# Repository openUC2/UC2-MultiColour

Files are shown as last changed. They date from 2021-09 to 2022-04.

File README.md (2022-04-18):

# openUC2 Multicolour Fluorescence 

Here we present some modules that will help you to first join different laser/light sources using a tunable dichroic mirror and linear dichroic filter switchers. Both modules can direclty snap into the UC2 system.
Curious to see what this looks like? Scroll to the very bottom of the page.

<p align="center">
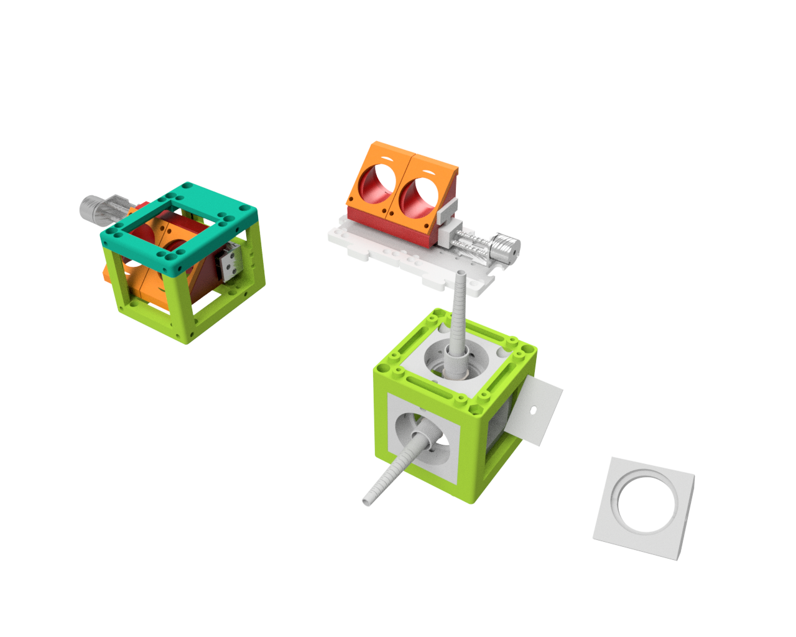
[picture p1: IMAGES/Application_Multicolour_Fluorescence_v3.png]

</p>

**Figure 1:** *(From-left-to-right) Compact linear filter switch that mounts the way that a beam couples from "behind"; same filter switcher, but beam enters from above; Laser beam combiner*

***Features:***
* Switch flourescence filters/dichroics linearly
* Align two beams w.r.t. each other
* Low-cost
* Integrate into the UC2 system

## In-Action

The filter switcher basically works like the one below. This version is deprecated, but the principle remains the same. 

<p align="center">

</p>

# Software

## Firmware 

The laser control and motion of the filter is done by the [UC2-REST](https://github.com/openUC2/UC2-REST) firmware. It is a work-in-progress and we suggest you to reach out to us through an issue when you're keen on using the software

## GUI/Controlsoftware

We forked the beautiful [ImSwitch](https://github.com/kasasxav/ImSwitch/) and adapted many functionalities (e.g. Filter swtichting) into their framework. The [beniroquai fork](https://github.com/beniroquai/ImSwitch/) implements the above mentioned Firmware [UC2-REST](https://github.com/openUC2/UC2-REST). Also here: It is a work-in-progress and we encourage you to reach out to us if you need help. :-)

## Python Code

A ESP32-Python client to control the motors that are connected to e.g. the CNC-Shield v3 can be found here [ESP32Client.py](https://github.com/openUC2/UC2-REST/blob/master/PYTHON/ESP32Client.py).

# Hardware - Beamcombiner

Below we describe how the device can be build and assembled in order to replicate the whole system as shown in the rendering above. One needs additional parts that can be found in the core [openUC2 repository](https://github.com/openUC2/UC2-GIT).

## Bill of material

Below you will find all components necessary to build the beamcombiner

### 3D printing files

All these files in the folder [./STL/Beamcombiner](./STL/Beamcombiner) need to be printed. We used a Prusa i3 MK3 using PLA Prusament (Galaxy Black) at layer height 0.3 mm and infill 30%.

Additionally you need 1x Cube.

<p align="center">
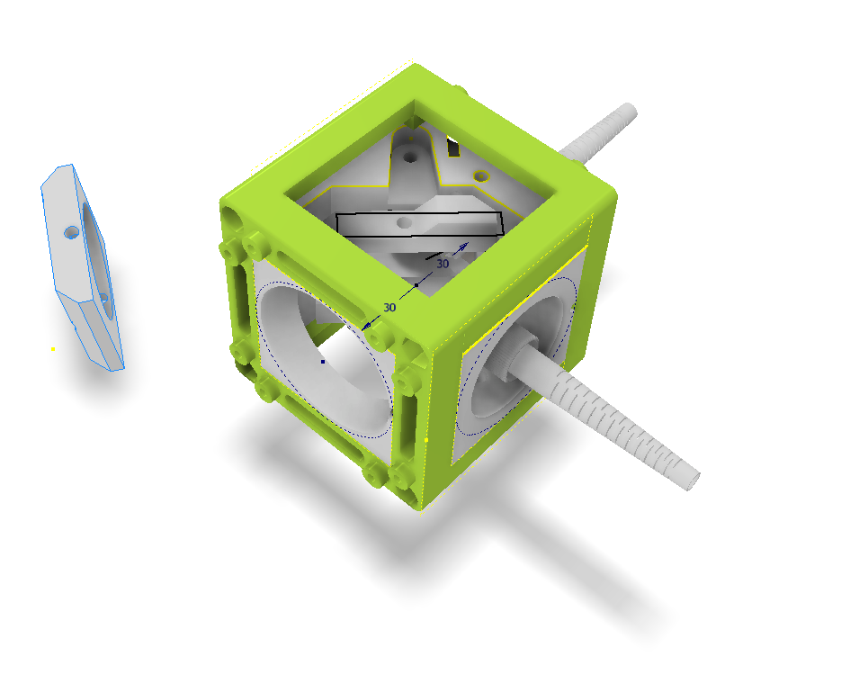
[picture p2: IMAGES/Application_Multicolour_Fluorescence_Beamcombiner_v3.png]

</p>

### Additional parts
This is used in the current version of the setup

|  Type | Details  |  Price | Link  |
|---|---|---|---|
| Dichroic mirror | Depending on your two wavelengths (25mm diameter or 25x16mm, chosoe adapter accordingly) |  10-100 € | [Comar](https://www.comaroptics.com/components/filters/dichroic-filters/long-pass-dichroic-filters)  |
| (optional) Fiber coupled laser | Depending on your system (e.g. MiCost, see SQUID paper) |  10-100 € | [MiCost](micost.com)  |
| (optional) Fiber adapter | 2x Thorlabs SM1FC |  15 € | [Thorlabs](Thorlabs.com)  |
| M3 screws | For kinematic mounting (non magnetic will be ok) |  1 € | [various](amazon.com)  |
| O-ring | 2x to add backtracing force; 10-15mm diameter |  1 € | [various](amazon.com)  |

### Design files
The original design files are in the [INVENTOR](./INVENTOR) folder. 

### Electronics
We develop a dedicated Electronics module called [UC2 Feather](https://github.com/openUC2/UC2_Feather/). Alternatively you can use an ESP32 Wemos d32 in conjuction with an CNC Shield v3.

### Assembly of the DEVICE

***1.*** *These are the parts needed for the DEVICE*

<p align="center">
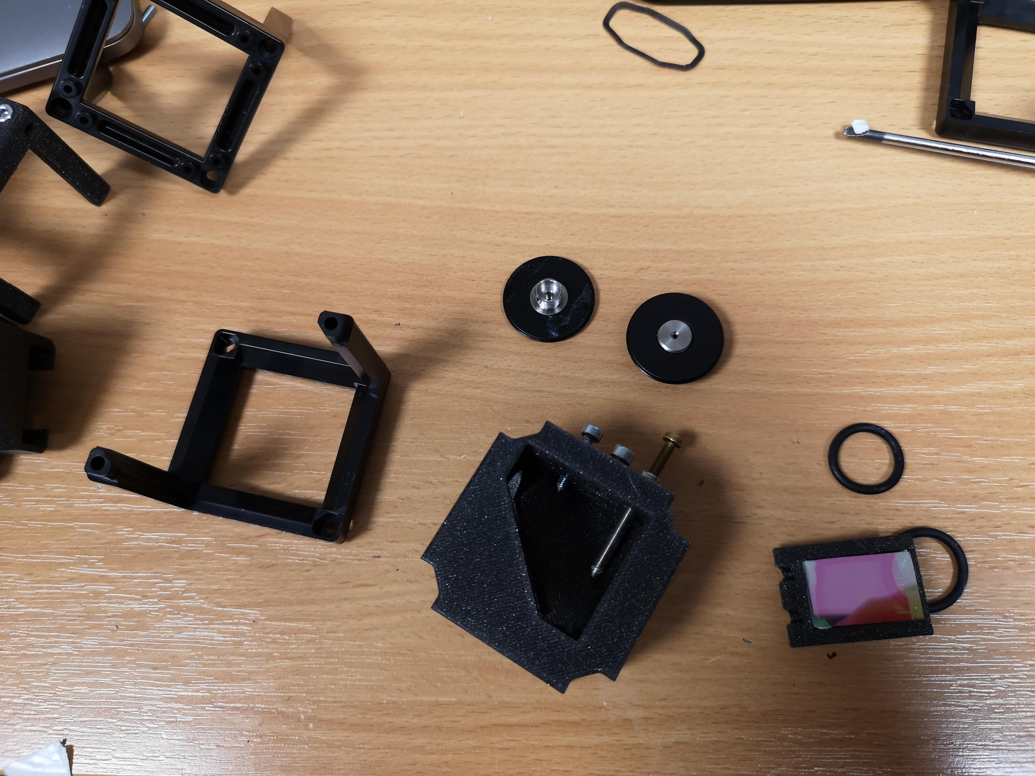
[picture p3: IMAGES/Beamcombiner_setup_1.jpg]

</p>

***2.*** *Start by adding the filter to the holder*

<p align="center">
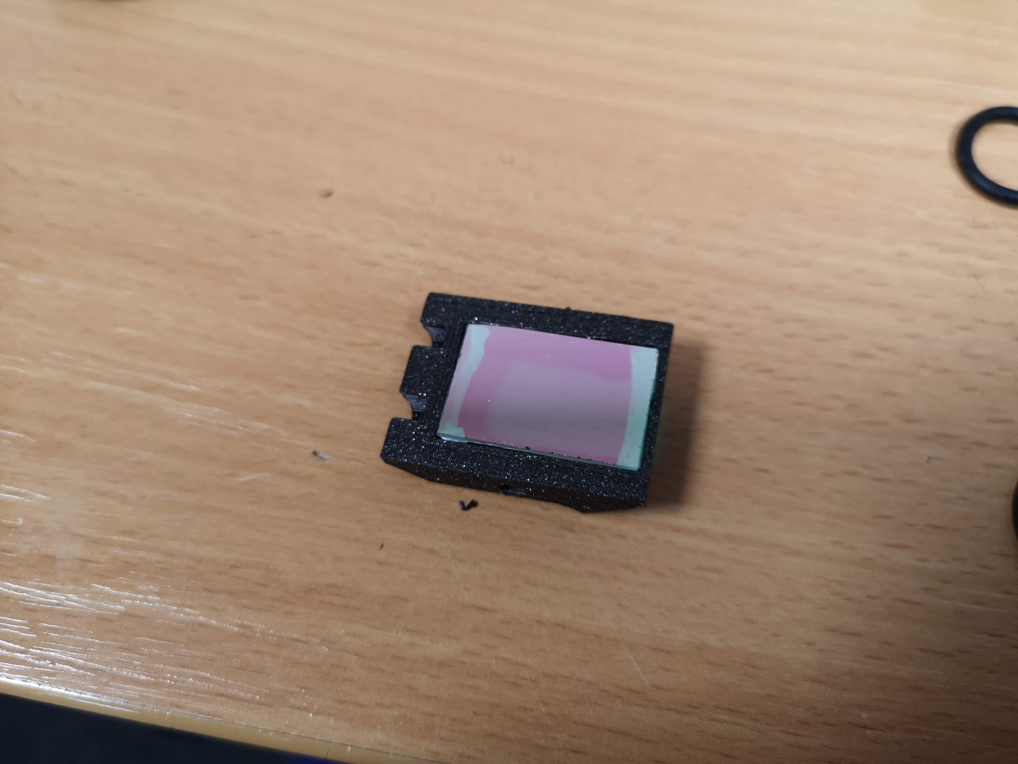
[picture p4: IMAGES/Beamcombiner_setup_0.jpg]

</p>

***3.*** *Add screws everywhere and also add the o-rings* Hint: The screws have been moved to an 45° angle to provide better force ratio (?); If thisneeds more explanation please reach out to us. Hint2: The screws should be pointed so that they fit into the 3D printed grooves from the kinematic mount!

<p align="center">
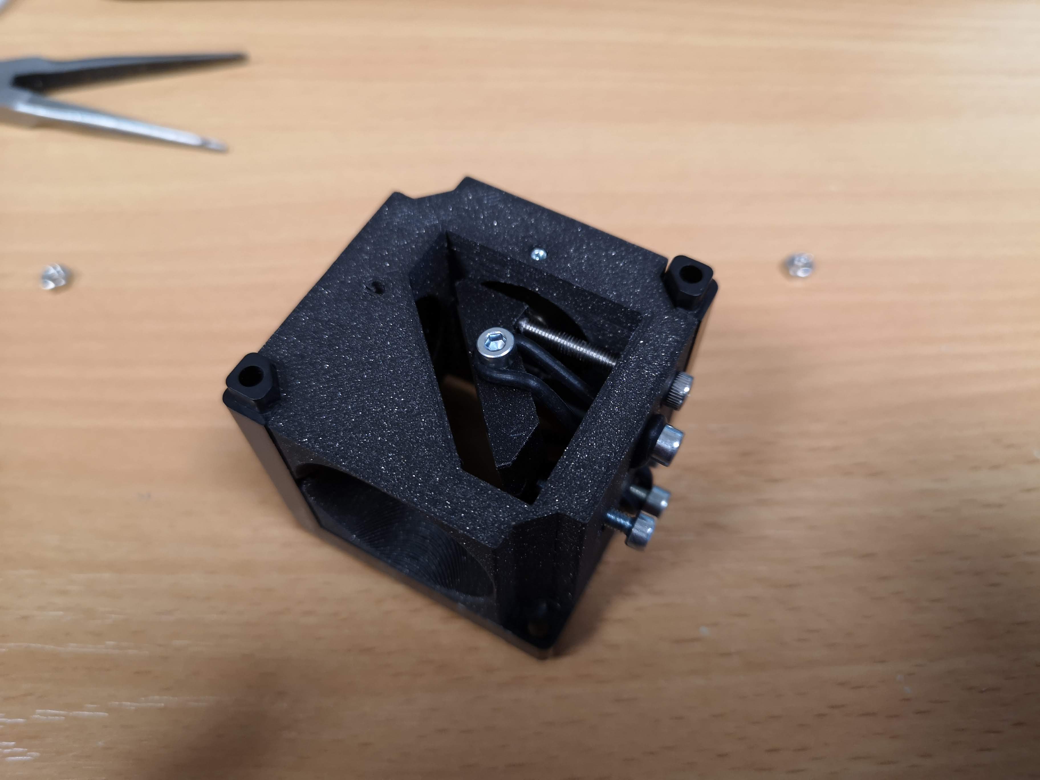
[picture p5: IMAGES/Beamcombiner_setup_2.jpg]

</p>

<p align="center">
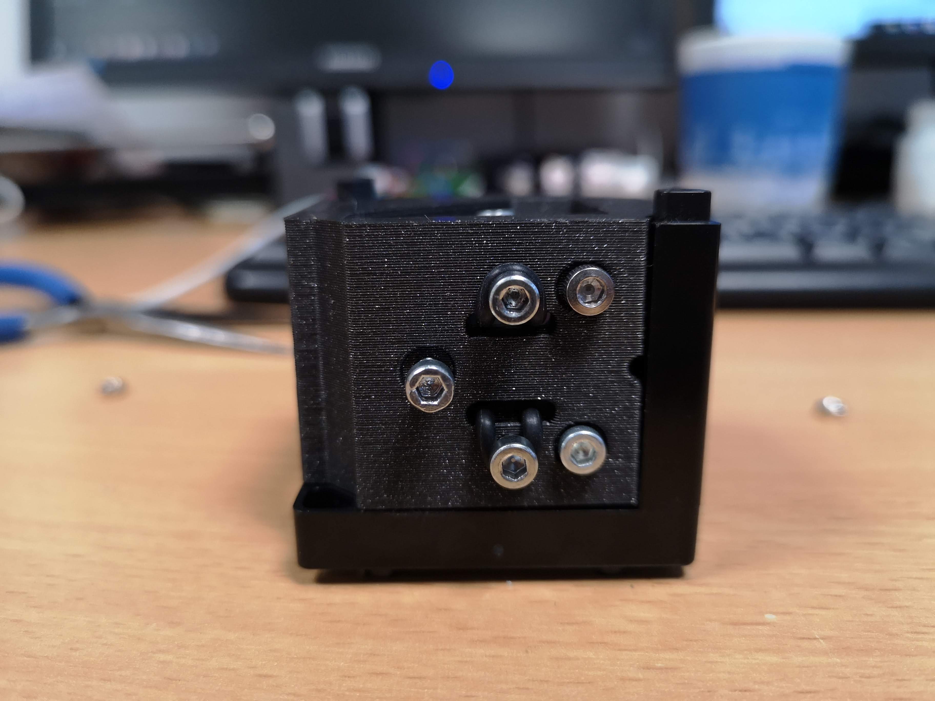
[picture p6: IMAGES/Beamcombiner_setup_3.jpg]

</p>

***4.*** *Add the fiber mounts *

<p align="center">
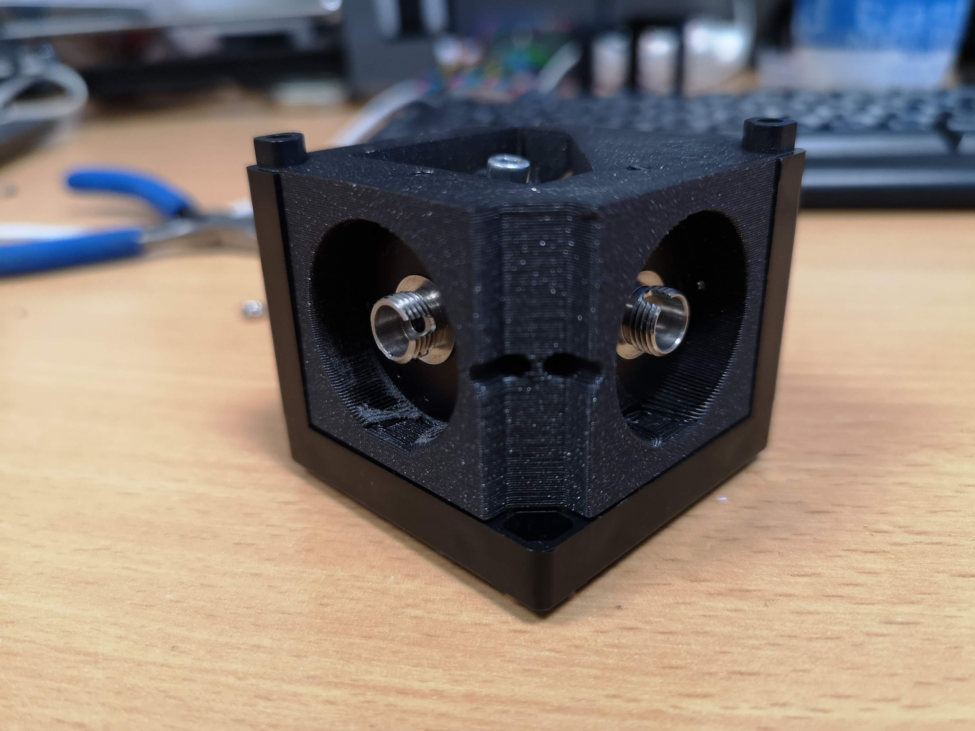
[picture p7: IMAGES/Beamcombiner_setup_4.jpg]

</p>

<p align="center">
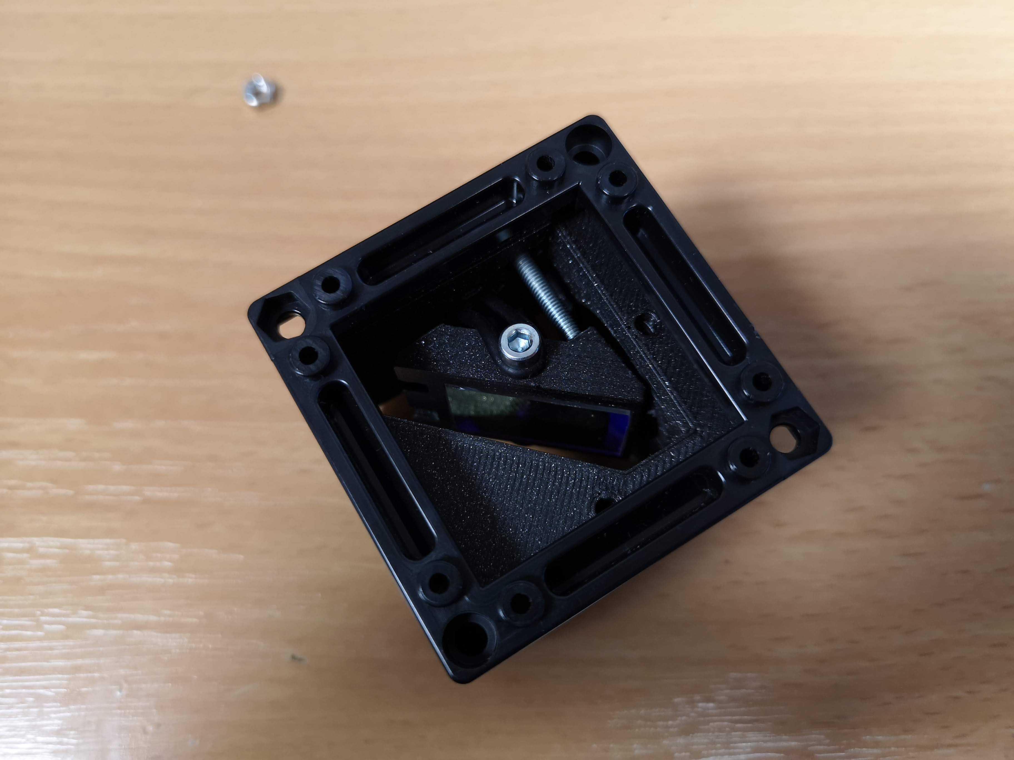
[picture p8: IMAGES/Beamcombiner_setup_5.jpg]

</p>

***5.*** *Add the laser fibers*

<p align="center">
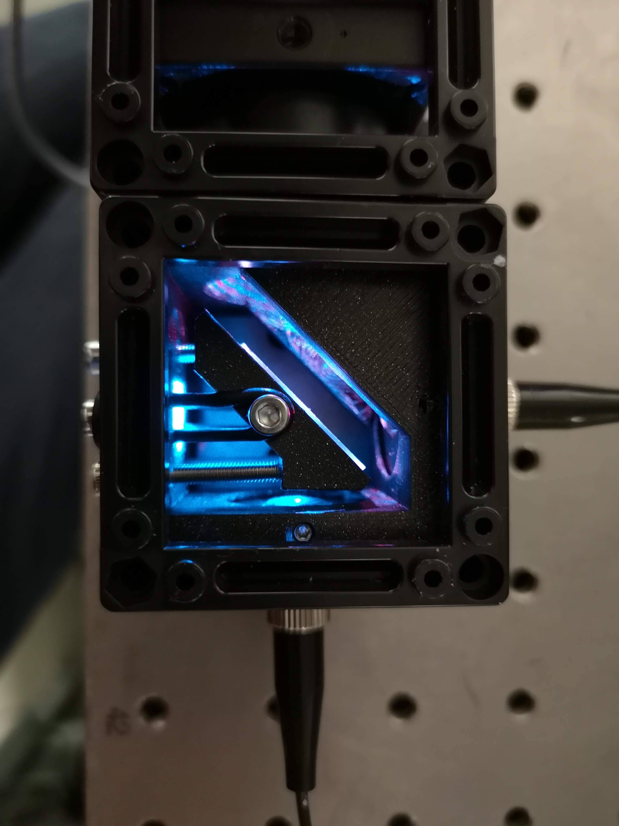
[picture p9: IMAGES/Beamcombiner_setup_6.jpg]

</p>

***6.*** *Align the two beams so that the two circles match perfectly at various places along the optical axis* Hint: Laser safety!

<p align="center">
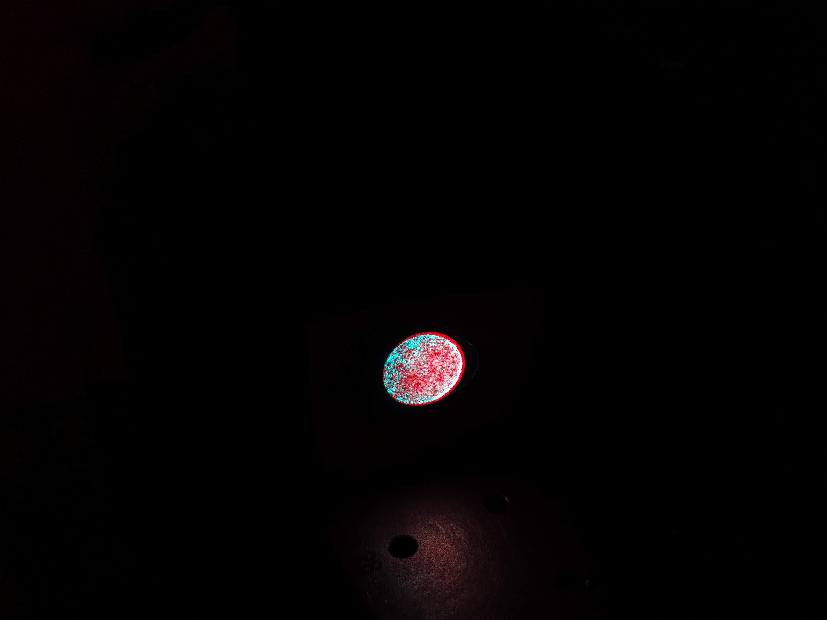
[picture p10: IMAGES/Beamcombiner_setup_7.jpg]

</p>

<p align="center">
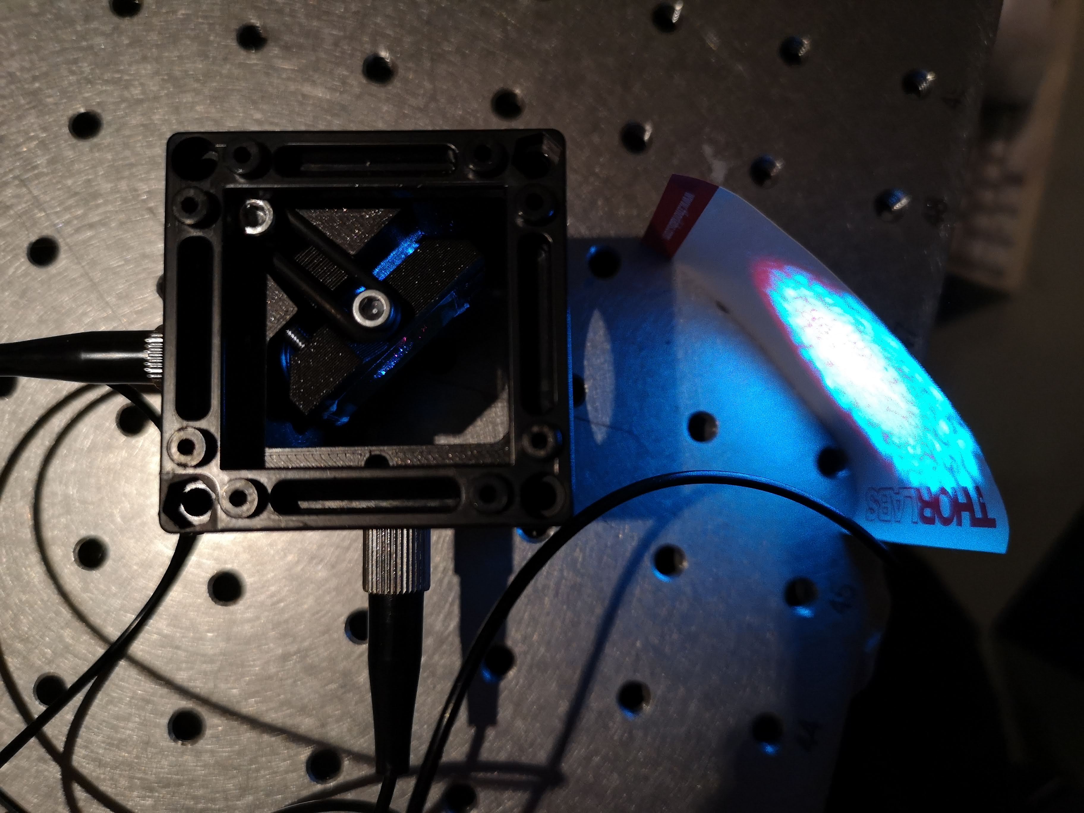
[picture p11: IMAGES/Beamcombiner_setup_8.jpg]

</p>

<p align="center">
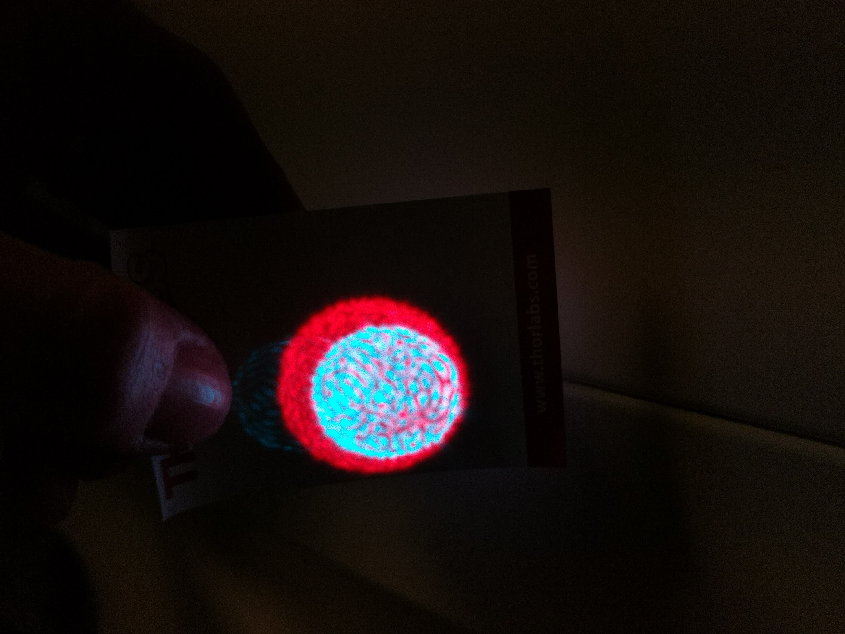
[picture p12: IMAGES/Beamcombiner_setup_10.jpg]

</p>

***7.*** *DONE! LOOK AT THE BEAUTY!*

<p align="center">
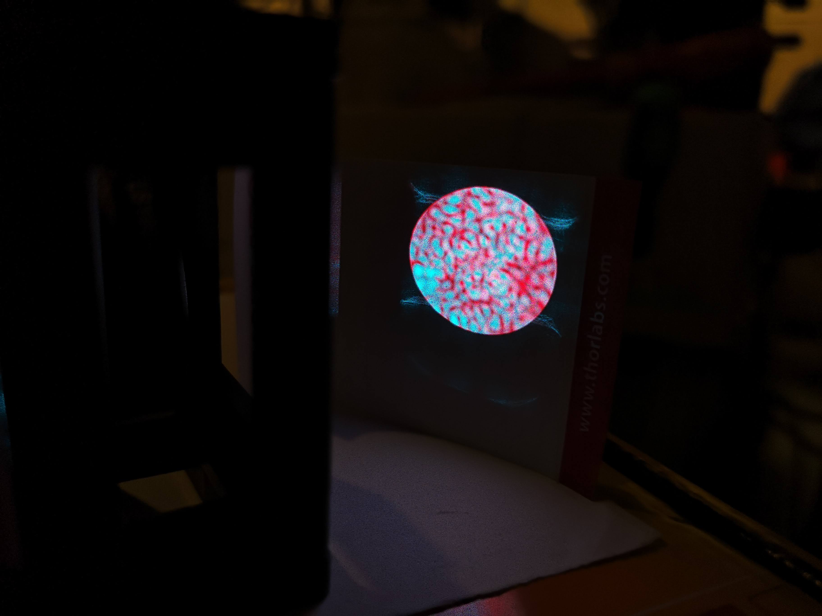
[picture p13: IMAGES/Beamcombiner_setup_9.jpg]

</p>

# Hardware - Beamcombiner

Below we describe how the device can be build and assembled in order to replicate the whole system as shown in the rendering above. One needs additional parts that can be found in the core [openUC2 repository](https://github.com/openUC2/UC2-GIT).

## Bill of material

Below you will find all components necessary to build the beamcombiner

### 3D printing files

All these files in the folder [./STL/Beamcombiner](./STL/Beamcombiner) need to be printed. We used a Prusa i3 MK3 using PLA Prusament (Galaxy Black) at layer height 0.3 mm and infill 30%.

Additionally you need 1x Cube.

<p align="center">

</p>

<p align="center">
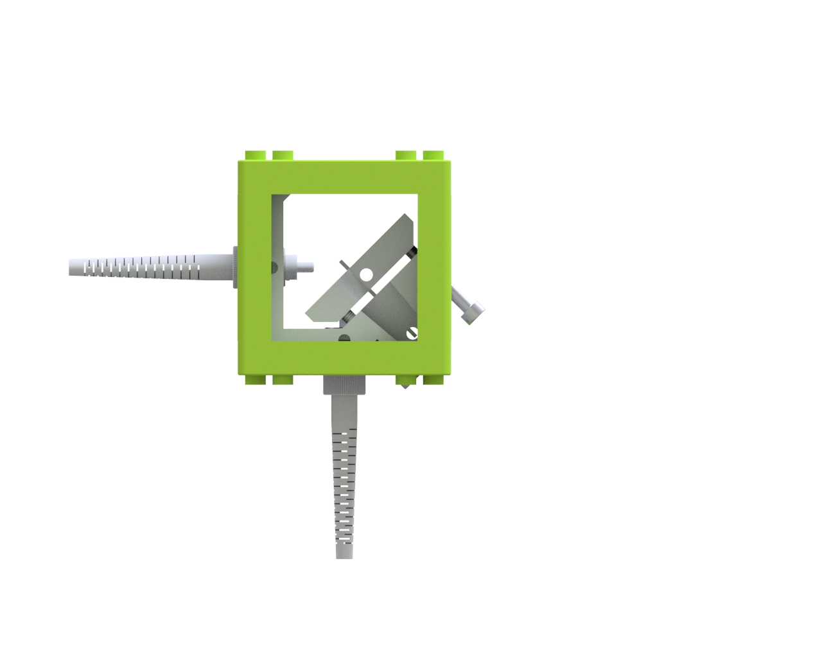
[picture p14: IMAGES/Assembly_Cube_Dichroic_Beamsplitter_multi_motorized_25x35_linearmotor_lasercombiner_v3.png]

</p>

### Additional parts
This is used in the current version of the setup

|  Type | Details  |  Price | Link  |
|---|---|---|---|
| Dichroic mirror | Depending on your two wavelengths (25mm diameter or 25x16mm, chosoe adapter accordingly) |  10-100 € | [Comar](https://www.comaroptics.com/components/filters/dichroic-filters/long-pass-dichroic-filters)  |
| (optional) Fiber coupled laser | Depending on your system (e.g. MiCost, see SQUID paper) |  10-100 € | [MiCost](micost.com)  |
| (optional) Fiber adapter | 2x Thorlabs SM1FC |  15 € | [Thorlabs](Thorlabs.com)  |
| M3 screws | For kinematic mounting (non magnetic will be ok) |  1 € | [various](amazon.com)  |
| O-ring | 2x to add backtracing force; 10-15mm diameter |  1 € | [various](amazon.com)  |

### Design files
The original design files are in the [INVENTOR](./INVENTOR) folder. 

### Electronics
We develop a dedicated Electronics module called [UC2 Feather](https://github.com/openUC2/UC2_Feather/). Alternatively you can use an ESP32 Wemos d32 in conjuction with an CNC Shield v3.

### Assembly of the DEVICE

***1.*** *These are the parts needed for the DEVICE*

<p align="center">

</p>

***2.*** *Start by adding the filter to the holder*

<p align="center">

</p>

***3.*** *Add screws everywhere and also add the o-rings* Hint: The screws have been moved to an 45° angle to provide better force ratio (?); If thisneeds more explanation please reach out to us. Hint2: The screws should be pointed so that they fit into the 3D printed grooves from the kinematic mount!

<p align="center">

</p>

<p align="center">

</p>

***4.*** *Add the fiber mounts *

<p align="center">

</p>

<p align="center">

</p>

***5.*** *Add the laser fibers*

<p align="center">

</p>

***6.*** *Align the two beams so that the two circles match perfectly at various places along the optical axis* Hint: Laser safety!

<p align="center">

</p>

<p align="center">

</p>

<p align="center">

</p>

***7.*** *DONE! LOOK AT THE BEAUTY!*

<p align="center">

</p>

# Hardware - Filterswitcher

Below we describe how the device can be build and assembled in order to replicate the whole system as shown in the rendering above. One needs additional parts that can be found in the core [openUC2 repository](https://github.com/openUC2/UC2-GIT).

## Bill of material

Below you will find all components necessary to build the filterswitcher

### 3D printing files

All these files in the folder [./STL/Beamcombiner](./STL/Beamcombiner) need to be printed. We used a Prusa i3 MK3 using PLA Prusament (Galaxy Black) at layer height 0.1 mm and infill 100%.
For the filter mount it is important to place this surface on the print bed surface so that it is perfectly flat. This way you can make sure that all dichroics are mounted under the same angle. 

Additionally you need several Cubes.

<p align="center">
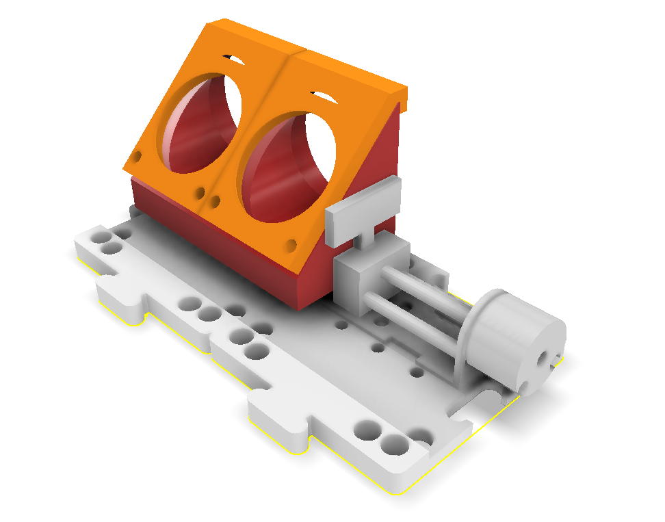
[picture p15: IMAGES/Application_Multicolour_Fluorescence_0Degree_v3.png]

</p>

*Here the beam enters from above (or below, depending on the orientation) and will be reflected horizontally*

<p align="center">
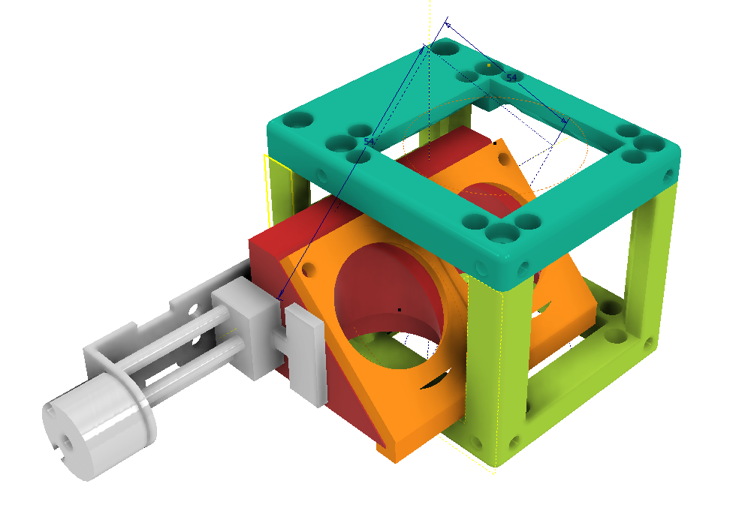
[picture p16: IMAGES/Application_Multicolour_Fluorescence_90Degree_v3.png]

</p>

*Here the beam enters from the side and will be reflected vertically (good for inverted microscopes)*

***HINT***:  you can have 3 filters too

### Additional parts
This is used in the current version of the setup

|  Type | Details  |  Price | Link  |
|---|---|---|---|
| Dichroic mirror | Depending on your two wavelengths (25mm diameter o) |  10-200 € | [Thorlabs](thorlabs.com)  |
| Emission filter | Depending on your two wavelengths (25mm diameter o) |  10-200 € | [Thorlabs](thorlabs.com)  |
| Linear Motor | DC 12V Hub 80mm 
Stepper Screw 2-Phase |  10-100 € | [Amazon](https://www.amazon.de/gp/product/B07X6J8C3T/ref=ox_sc_act_title_1?smid=A119AWRA5YL9T1&psc=1)  |
| M3 screws | For kinematic mounting (non magnetic will be ok) |  1 € | [various](amazon.com)  |
| O-ring | 2x to add backtracing force; 10-15mm diameter |  1 € | [various](amazon.com)  |

### Design files
The original design files are in the [INVENTOR](./INVENTOR) folder. 

### Electronics
We develop a dedicated Electronics module called [UC2 Feather](https://github.com/openUC2/UC2_Feather/). Alternatively you can use an ESP32 Wemos d32 in conjuction with an CNC Shield v3.

### Assembly of the DEVICE

***1.*** *These are the parts needed for the DEVICE*

<p align="center">
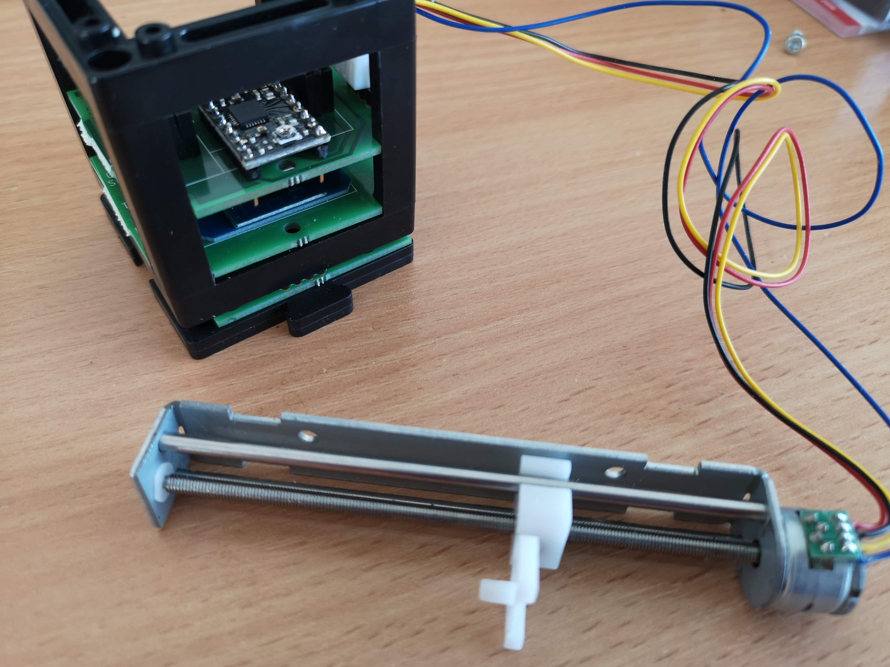
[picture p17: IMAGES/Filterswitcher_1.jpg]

</p>

<p align="center">
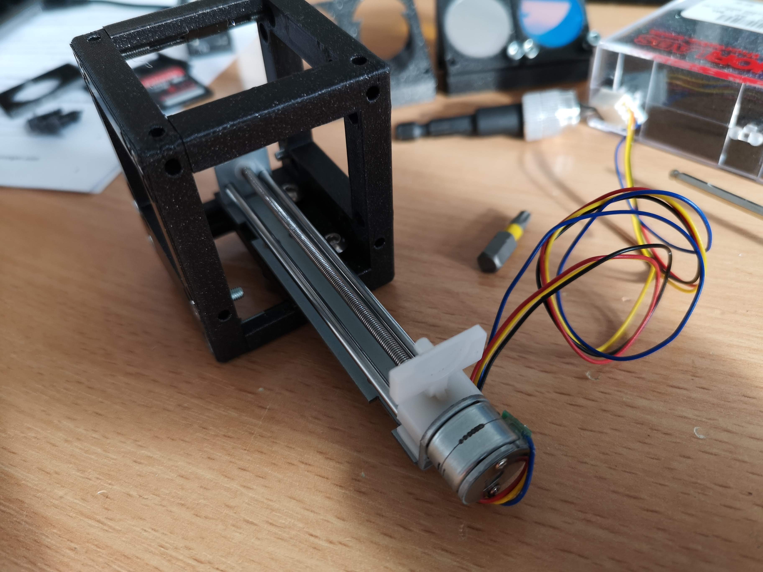
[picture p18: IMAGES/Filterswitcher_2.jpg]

</p>

Here moves the motor, glue the white pin to the filterholder

<p align="center">
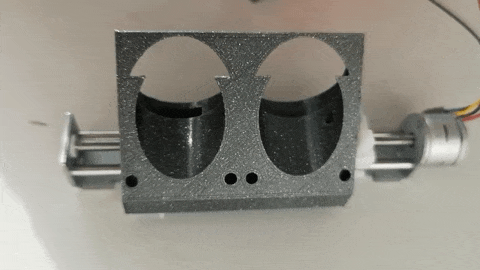
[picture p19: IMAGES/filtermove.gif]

</p>

***2.*** Mount the Slide with M3 screws to the Cube
<p align="center">
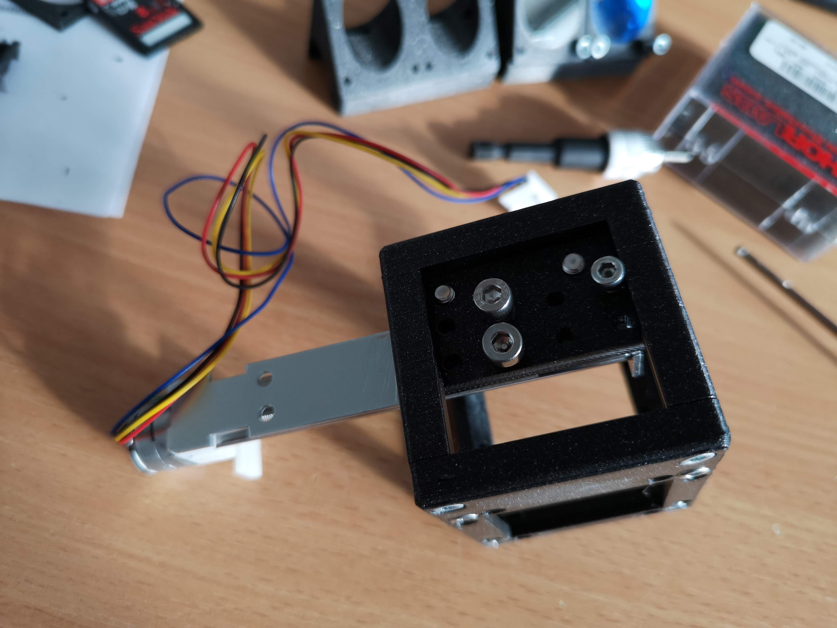
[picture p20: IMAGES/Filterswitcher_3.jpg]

</p>

***3.*** Add the filters with additional M3 screws

<p align="center">
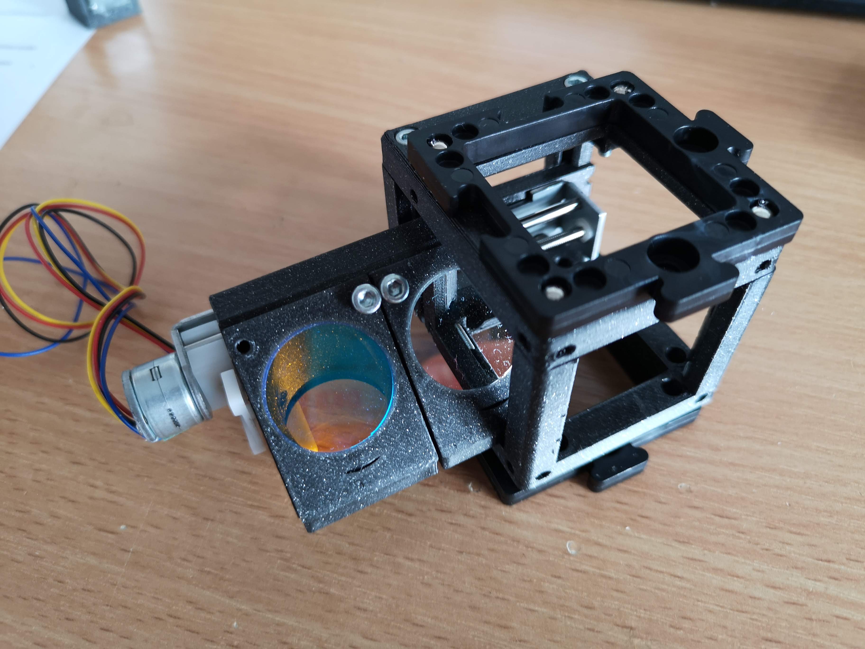
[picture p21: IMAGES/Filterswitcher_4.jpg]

</p>

***4.*** Add this to the setup

<p align="center">
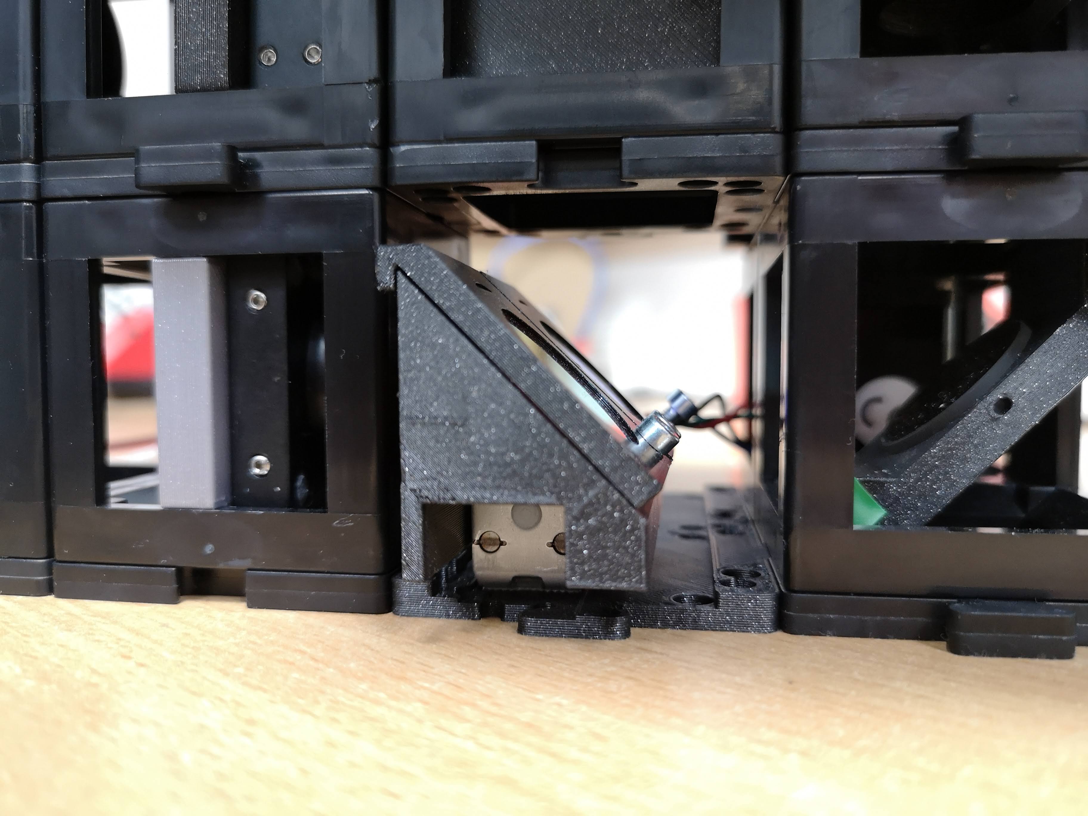
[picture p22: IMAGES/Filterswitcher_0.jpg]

</p>

## Showcase

Here we present a z-stack of infected epithelia cells with two different colours (GFP+AF647).

<p align="center">

</p>

### In a setup

***Inside an upright microscope.***

<p align="center">
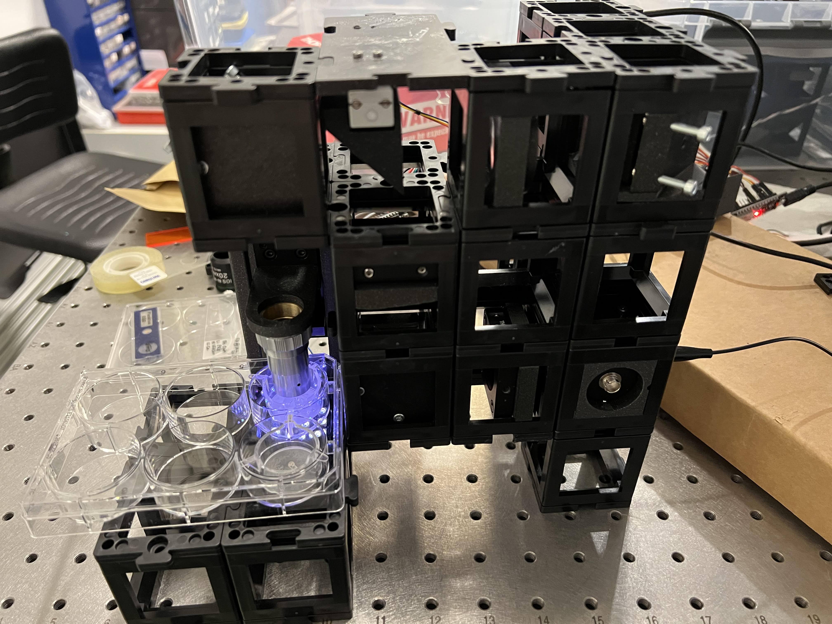
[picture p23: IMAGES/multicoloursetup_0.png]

</p>

The filter is hanging here. 

<p align="center">
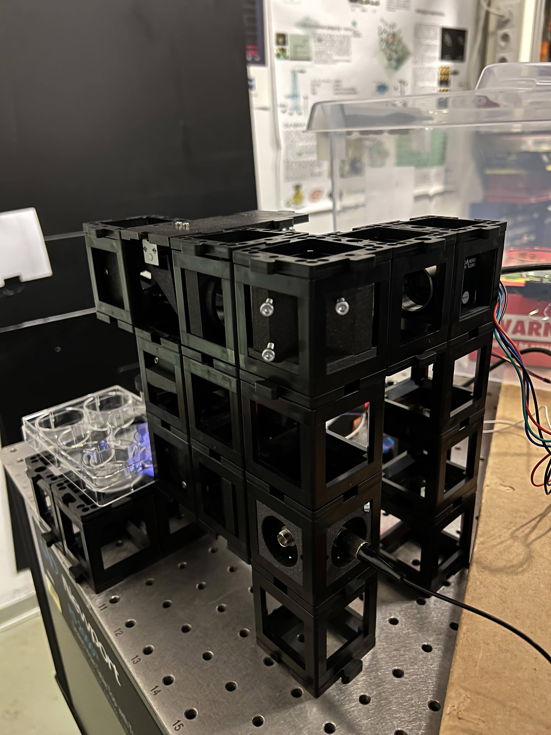
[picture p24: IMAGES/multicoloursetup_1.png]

</p>

## Deprecated

In older releases, we were working on these designs:

### Filter revolver

<p align="center">
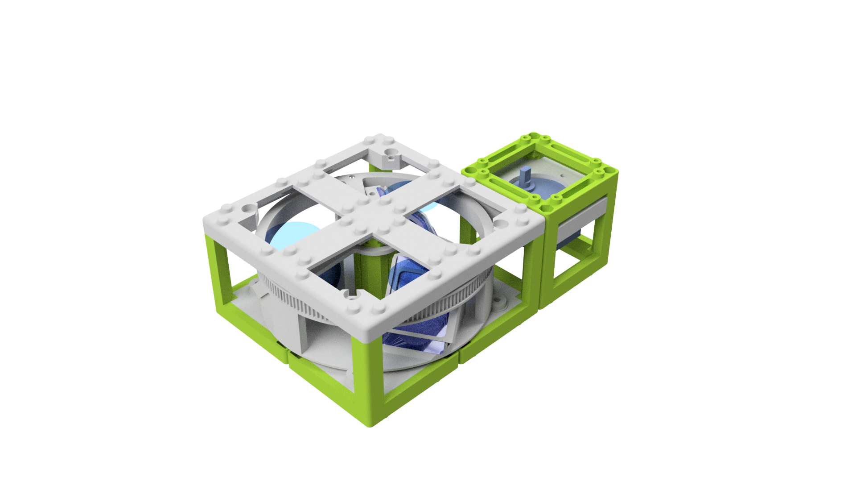
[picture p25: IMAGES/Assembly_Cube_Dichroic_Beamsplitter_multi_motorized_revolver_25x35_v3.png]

</p>

- could be very fast
- never "on-axis"
- every filter has a different angle w.r.t. the incoming beam
- hard to align

### Linear filter with MGN12 slide

<p align="center">
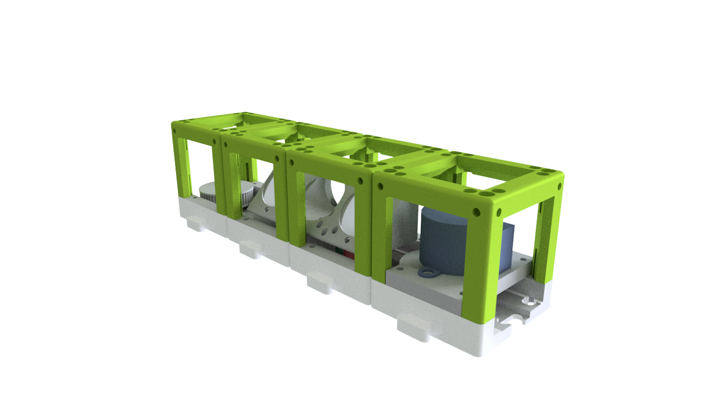
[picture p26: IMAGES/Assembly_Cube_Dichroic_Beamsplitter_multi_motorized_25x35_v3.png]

</p>

- could be very precise
- slow motor
- complicated to build 
- low-cost 
- a bit wiggely w.r.t the angle for each position (too compact 

## Further reading
- Low-cost stage scanner: [PLoS One](https://journals.plos.org/plosone/article?id=10.1371/journal.pone.0194063)
- MicroscoPi: [Biorxiv](https://micronoxford.com/microscopi-3d-printed-1)
- Incubot: [HardwareX](https://www.sciencedirect.com/science/article/pii/S2468067221000183)
- Opentrons [Website](www.opentrons.com)
- OpenFlexure Microscope [Website](https://openflexure.org/)
- openUC2 [Github](https://github.com/openUC2/)

## Get Involved

This project is open so that anyone can get involved. You don't even have to learn CAD designing or programming. Find ways you can contribute in  [CONTRIBUTING](CONTRIBUTING.md)

## License and Collaboration

This project is open-source and is released under the CERN open hardware license. Our aim is to make the kits commercially available.
We encourage everyone who is using our Toolbox to share their results and ideas, so that the Toolbox keeps improving. It should serve as a easy-to-use and easy-to-access general purpose building block solution for the area of STEAM education. All the design files are generally for free, but we would like to hear from you how is it going.

You're free to fork the project and enhance it. If you have any suggestions to improve it or add any additional functions make a pull-request or file an issue.

Please find the type of licenses [here](./License.md)

REMARK: All files have been designed using Autodesk Inventor 2019 (EDUCATION)

## Credits
If you find this project useful, please like this repository, follow us on Twitter and cite the webpage! :-)

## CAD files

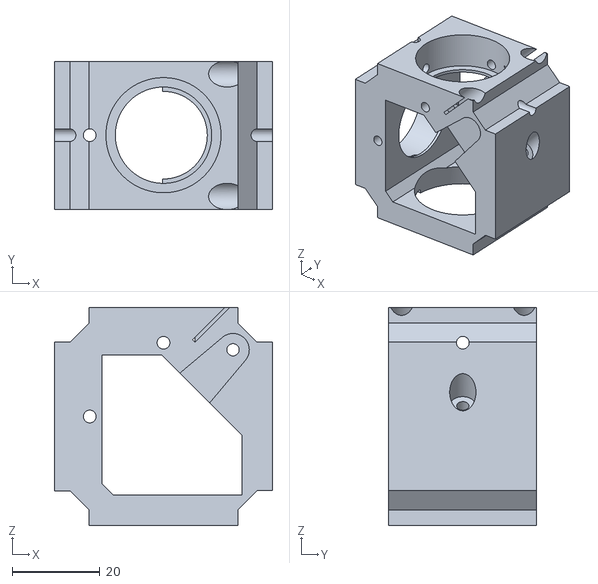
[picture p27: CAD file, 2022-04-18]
STL/Beamcombiner/Assembly_Cube_Fibercombiner_v3_20_Cube_Insert_Fibercombiner_FPC_v3_3.stl
49.8 x 33.8 x 49.8

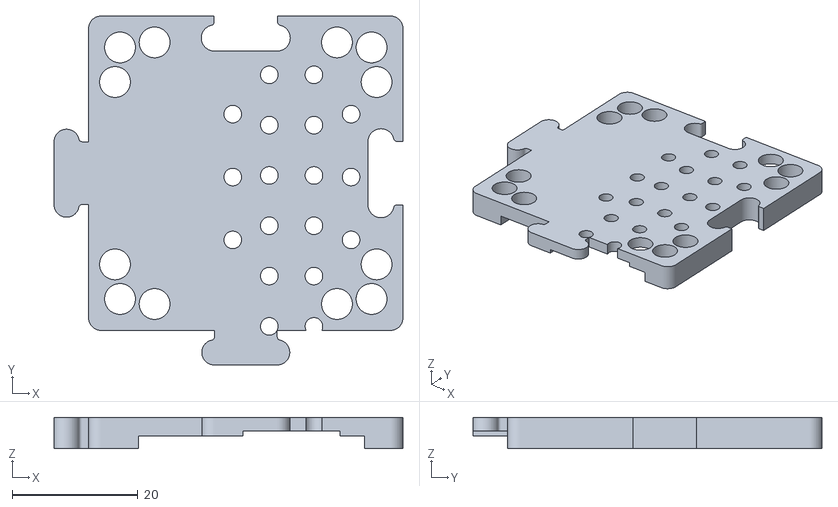
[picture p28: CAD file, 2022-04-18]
STL/FilderSwticher0Degree/Assembly_Cube_Dichroic_Beamsplitter_multi_motorized_25x35_linearmotor_v3_20_Cube_Insert_Beamsplittercube_motorized_base_slide_linearmotor_5.stl
55.5 x 55.5 x 5.00

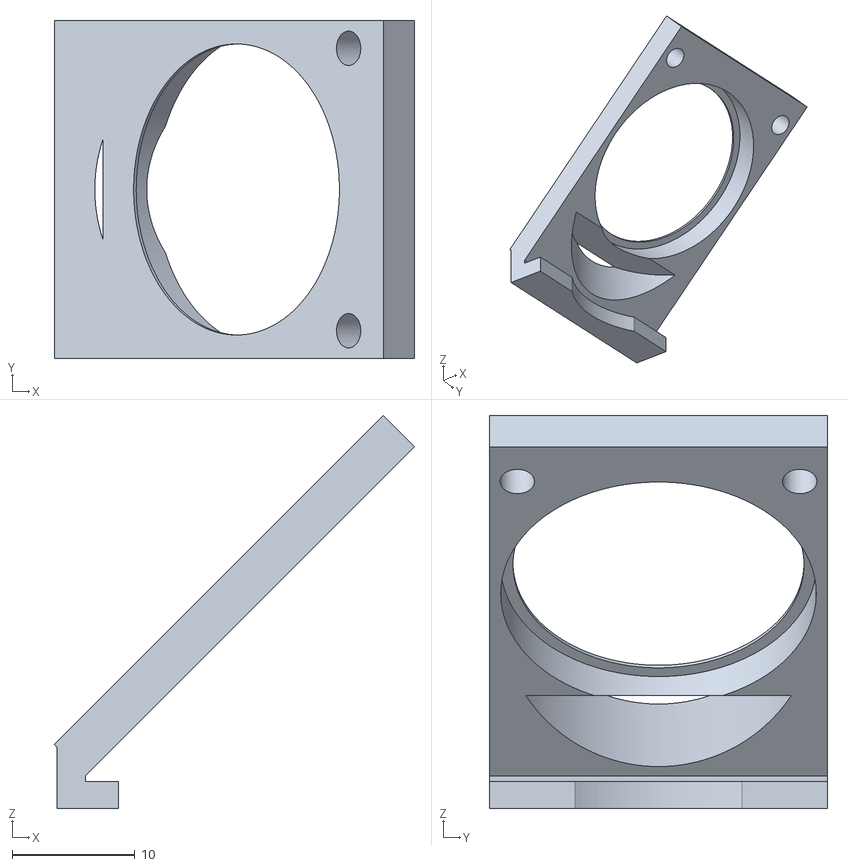
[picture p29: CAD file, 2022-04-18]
STL/FilderSwticher90Degree/Assembly_Cube_Dichroic_Beamsplitter_multi_motorized_25x35_linearmotor_90degreerot_v3_30_Cube_Insert_Filter_Revolver_Filter_lid_linearmotor_7.stl
29.3 x 27.5 x 32.0

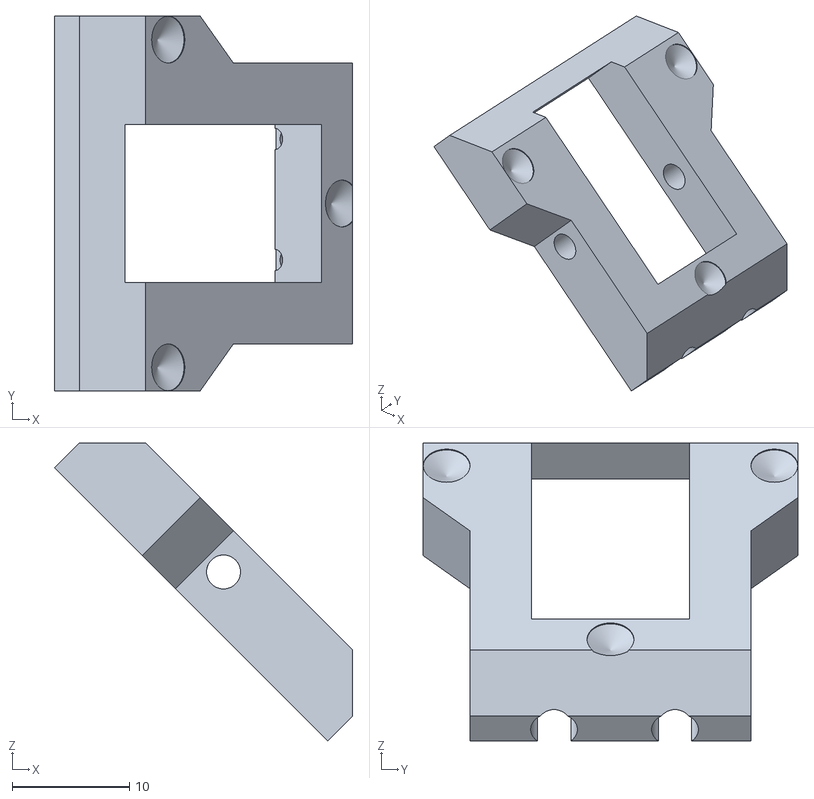
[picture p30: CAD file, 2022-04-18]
STL/Beamcombiner/Assembly_Cube_Fibercombiner_v3_20_Cube_Insert_Fibercombiner_FPC_filtermount_v3_7.stl
25.5 x 32.0 x 25.5

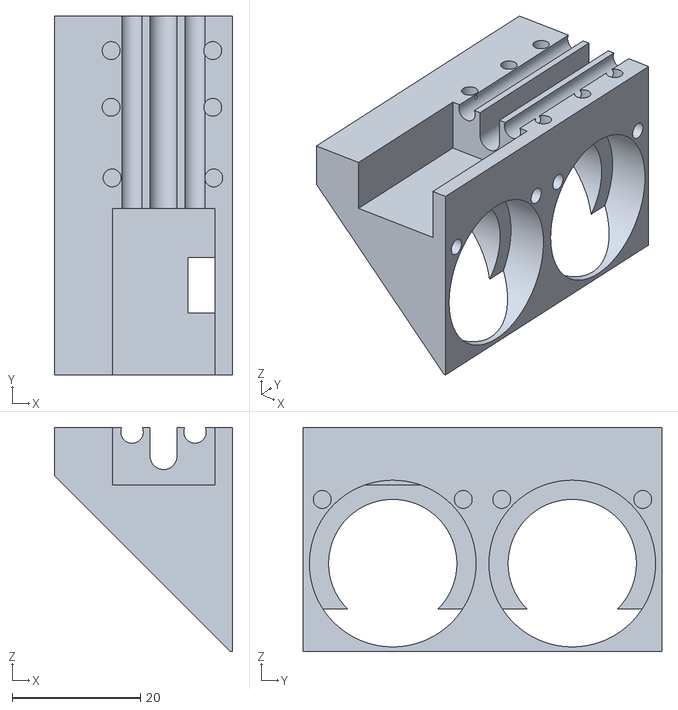
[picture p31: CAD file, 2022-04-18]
STL/FilderSwticher0Degree/Assembly_Cube_Dichroic_Beamsplitter_multi_motorized_25x35_linearmotor_v3_30_Cube_Insert_Filter_Revolver_Filter_base_triple_linearmotor_1.stl
27.8 x 56.0 x 35.0

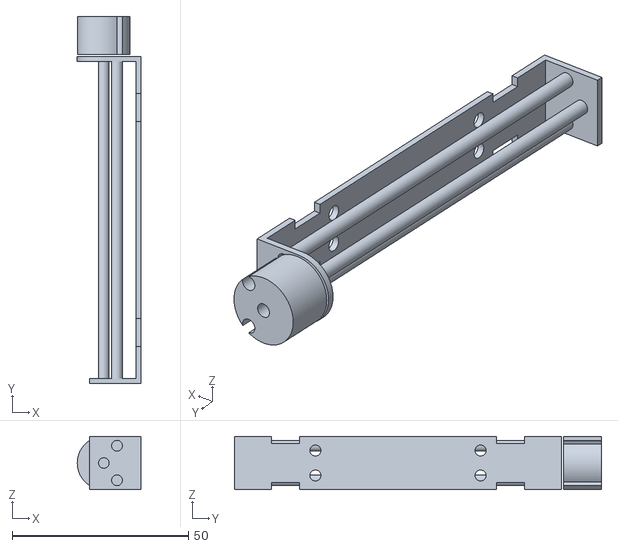
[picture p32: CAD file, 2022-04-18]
STL/FilderSwticher90Degree/Assembly_Cube_Dichroic_Beamsplitter_multi_motorized_25x35_linearmotor_90degreerot_v3_00_Linear_Stepper_90mm_2.stl
18.0 x 104.3 x 15.1

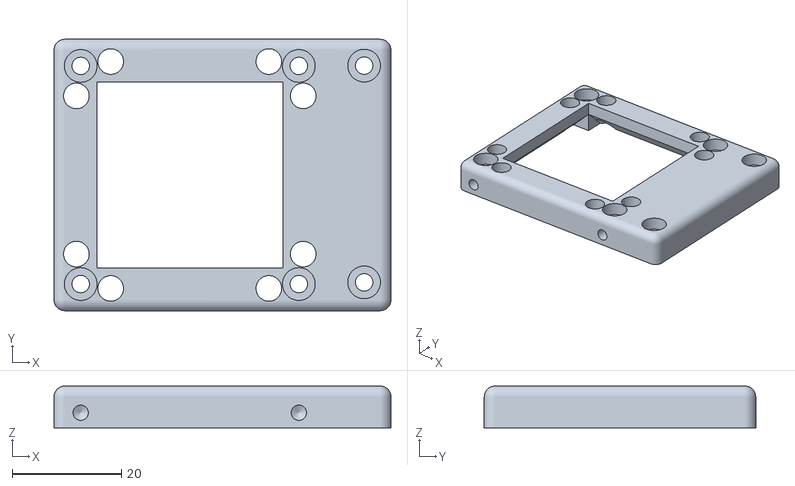
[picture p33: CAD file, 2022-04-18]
STL/FilderSwticher90Degree/Assembly_Cube_Dichroic_Beamsplitter_multi_motorized_25x35_linearmotor_90degreerot_v3_20_Cube_Insert_Beamsplittercube_motorized_cube_LID_5.stl
61.8 x 49.8 x 7.70

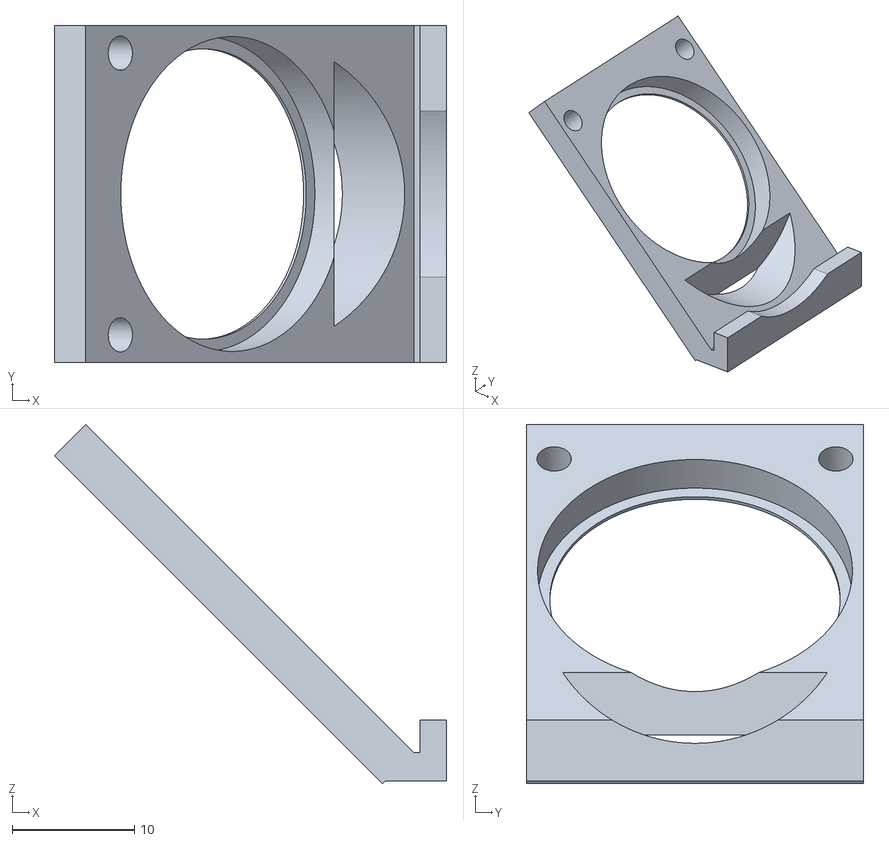
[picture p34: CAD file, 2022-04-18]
STL/FilderSwticher0Degree/Assembly_Cube_Dichroic_Beamsplitter_multi_motorized_25x35_linearmotor_v3_30_Cube_Insert_Filter_Revolver_Filter_lid_linearmotor_7.stl
32.0 x 27.5 x 29.3

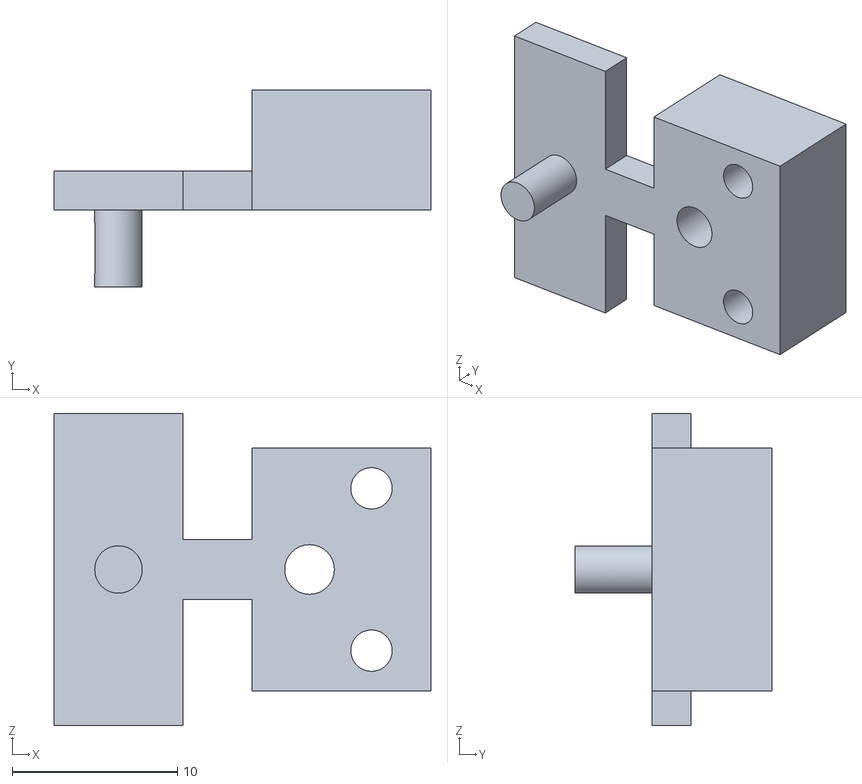
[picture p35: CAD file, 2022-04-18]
STL/FilderSwticher90Degree/Assembly_Cube_Dichroic_Beamsplitter_multi_motorized_25x35_linearmotor_90degreerot_v3_00_Linear_Stepper_90mm_slide_3.stl
22.8 x 11.9 x 18.9

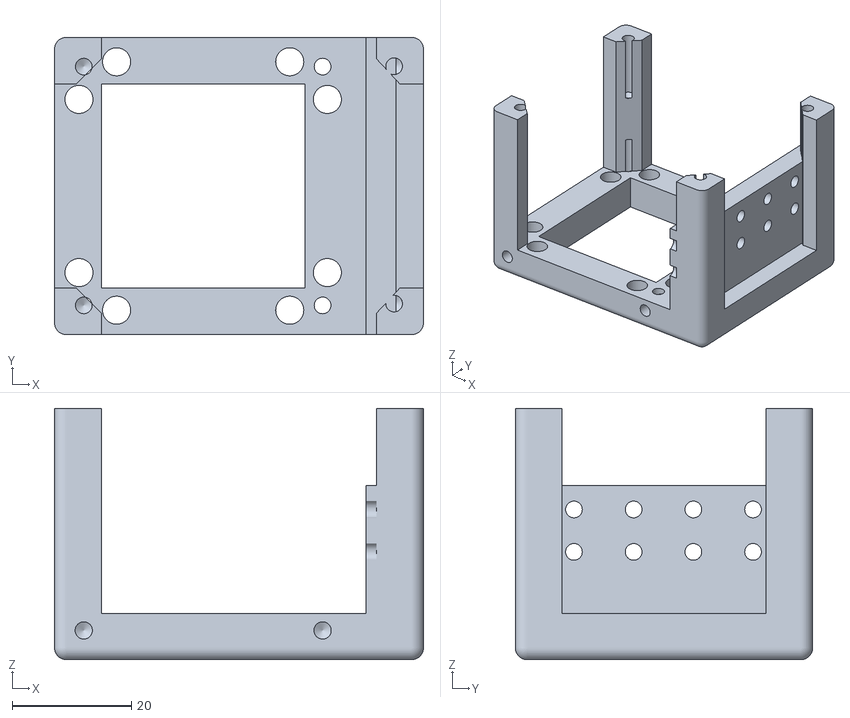
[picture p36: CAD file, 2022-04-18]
STL/FilderSwticher90Degree/Assembly_Cube_Dichroic_Beamsplitter_multi_motorized_25x35_linearmotor_90degreerot_v3_20_Cube_Insert_Beamsplittercube_motorized_cube_base_4.stl
61.8 x 49.8 x 42.1

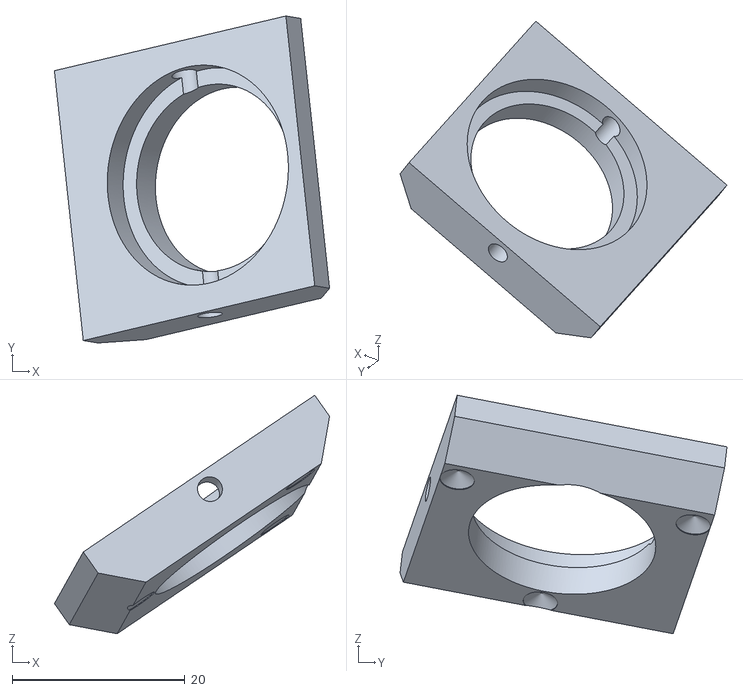
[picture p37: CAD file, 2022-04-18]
STL/Beamcombiner/Assembly_Cube_Fibercombiner_v3_20_Cube_Insert_Fibercombiner_FPC_filtermount_Thorlabs25mm_v3_10.stl
31.9 x 37.9 x 27.6

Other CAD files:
STL/FilderSwticher90Degree/Assembly_Cube_Dichroic_Beamsplitter_multi_motorized_25x35_linearmotor_90degreerot_v3_30_Cube_Insert_Filter_Revolver_Filter_lid_linearmotor_6.stl
STL/FilderSwticher0Degree/Assembly_Cube_Dichroic_Beamsplitter_multi_motorized_25x35_linearmotor_v3_20_Cube_Insert_Beamsplittercube_motorized_base_slide_linearmotor_4.stl
STL/FilderSwticher0Degree/Assembly_Cube_Dichroic_Beamsplitter_multi_motorized_25x35_linearmotor_v3_30_Cube_Insert_Filter_Revolver_Filter_lid_linearmotor_6.stl
STL/FilderSwticher0Degree/Assembly_Cube_Dichroic_Beamsplitter_multi_motorized_25x35_linearmotor_v3_00_Linear_Stepper_90mm_2.stl
STL/FilderSwticher0Degree/Assembly_Cube_Dichroic_Beamsplitter_multi_motorized_25x35_linearmotor_v3_00_Linear_Stepper_90mm_slide_3.stl
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

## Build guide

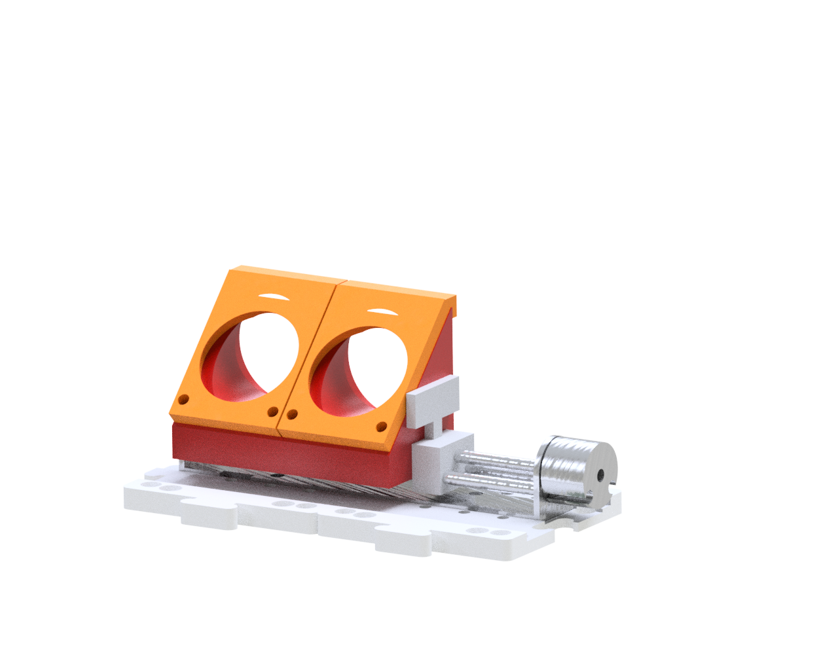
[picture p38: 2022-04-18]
IMAGES/Assembly_Cube_Dichroic_Beamsplitter_multi_motorized_25x35_linearmotor_v3.png

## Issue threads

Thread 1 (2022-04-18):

Review Documentation

beniroquai, 2022-04-18:
@ranranking you are the only one who build this piece. Would you mind to check if the updated README is plausible?

ranranking, 2022-04-18:
Sure, I can update the README

获取 Outlook for iOS<https://aka.ms/o0ukef>
________________________________
发件人: Benedict Diederich ***@***.***>
发送时间: Monday, April 18, 2022 8:26:21 AM
收件人: openUC2/UC2-MultiColour ***@***.***>
抄送: ranranking ***@***.***>; Assign ***@***.***>
主题: [openUC2/UC2-MultiColour] Review Documentation (Issue #1)

@ranranking<https://github.com/ranranking> you are the only one who build this piece. Would you mind to check if the updated README is plausible?

―
Reply to this email directly, view it on GitHub<https://github.com/openUC2/UC2-MultiColour/issues/1>, or unsubscribe<https://github.com/notifications/unsubscribe-auth/AMSPQ7KUTW2XYEIH66AVQY3VFT6A3ANCNFSM5TVCTFAQ>.
You are receiving this because you were assigned.Message ID: ***@***.***>

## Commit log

2021-09-15 Updated the assembly and rotating mechanism
    [10_Cube_1x1_IM.ipt, 10_Cube_Side_IM.ipt, 30_Cube_Insert_Filter_Revolver_Bearingmount_2_v3.ipt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]
2022-04-17 Updating CAD files for multicolour fluorescence imaging using UC2
    [00_30126G3-Step.ipt, 00_Chroma_Dichroic_25x,3x1.ipt, 00_Comar_Dichroic_16x25x0.2.ipt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]
2022-04-18 Cleaning up, adding BOM
    [00_Chroma_Dichroic_25x,3x1.ipt, 00_Comar_Filter_25Dia.ipt, 00_Stepper_Motor_28BYJ-48.ipt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]
2022-04-18 Huge cleanup and adding docuemntation
    [Assembly_Cube_Fibercombiner_v3_00_30126G3-Step_4.stl, Assembly_Cube_Fibercombiner_v3_00_30126G3-Step_5.stl, Assembly_Cube_Fibercombiner_v3_00_Comar_Dichroic_16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]
